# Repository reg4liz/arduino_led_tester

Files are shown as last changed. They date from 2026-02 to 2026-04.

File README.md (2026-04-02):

# arduino_led_tester
LED tester on atmega328 with adjustable current source.

## Glorious prototype
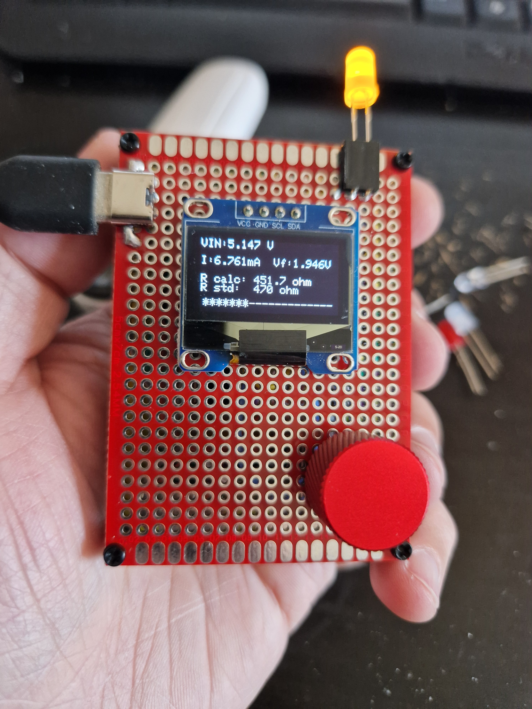
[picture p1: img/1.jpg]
Prototype


## Schematic
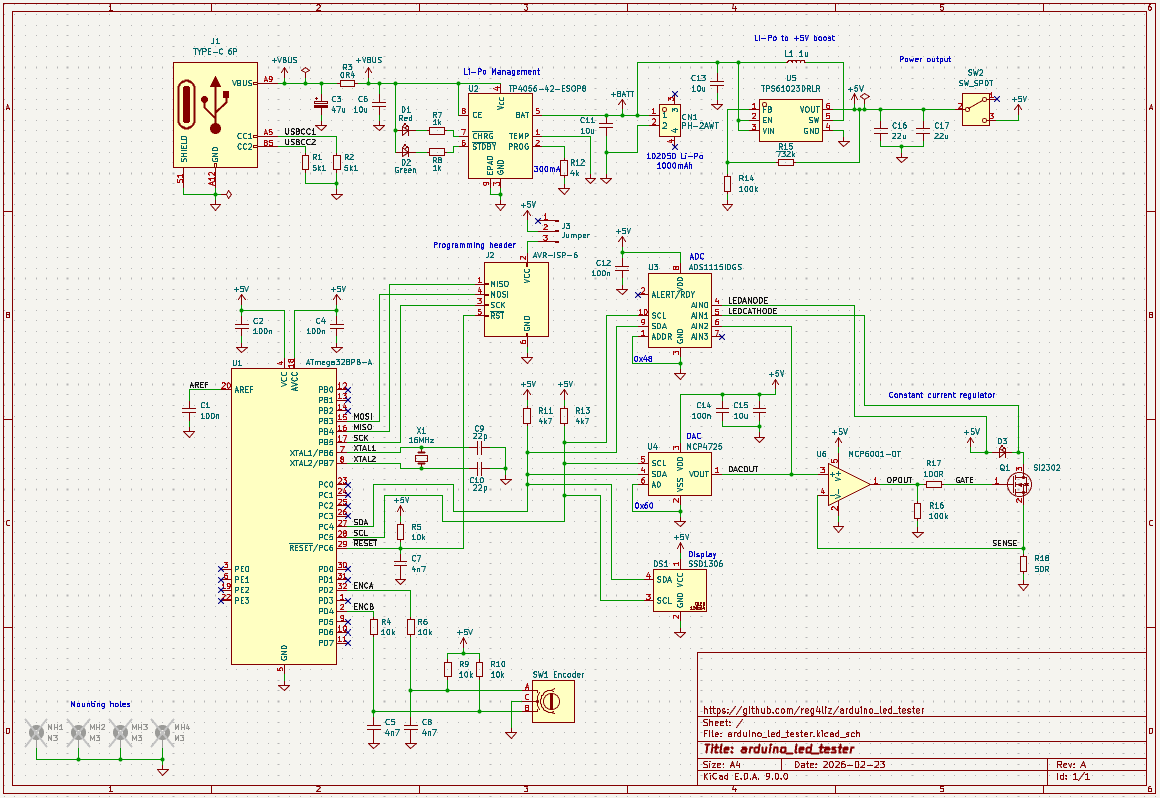
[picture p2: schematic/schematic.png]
Schematic


## Main components used for prototype
* [ATMEGA328P](https://www.digikey.com/en/products/detail/microchip-technology/ATMEGA328P-PU/1914589)
* [MCP6001 op-amp](https://www.digikey.com/es/products/detail/microchip-technology/MCP6001T-I-OT/551760)
* [SI2302CDS nmos](https://www.digikey.com/en/products/detail/vishay-siliconix/SI2302CDS-T1-GE3/1978729)
* [PEC12R-4025F-N0024 encoder](https://www.digikey.es/es/products/detail/bourns-inc/PEC12R-4025F-N0024/4499645)
* [ADS1115 ADC Module](https://aliexpress.com/item/1005006532275889.html)
* [MCP4725 DAC Module](https://aliexpress.com/item/1005007384695140.html)
* [SSD1306 128x64 OLED display](https://aliexpress.com/item/1005004355547926.html)

## TO-DO
* Full code re-write, at this time this is just a proof of concept to get it working quickly.
* Update components list.

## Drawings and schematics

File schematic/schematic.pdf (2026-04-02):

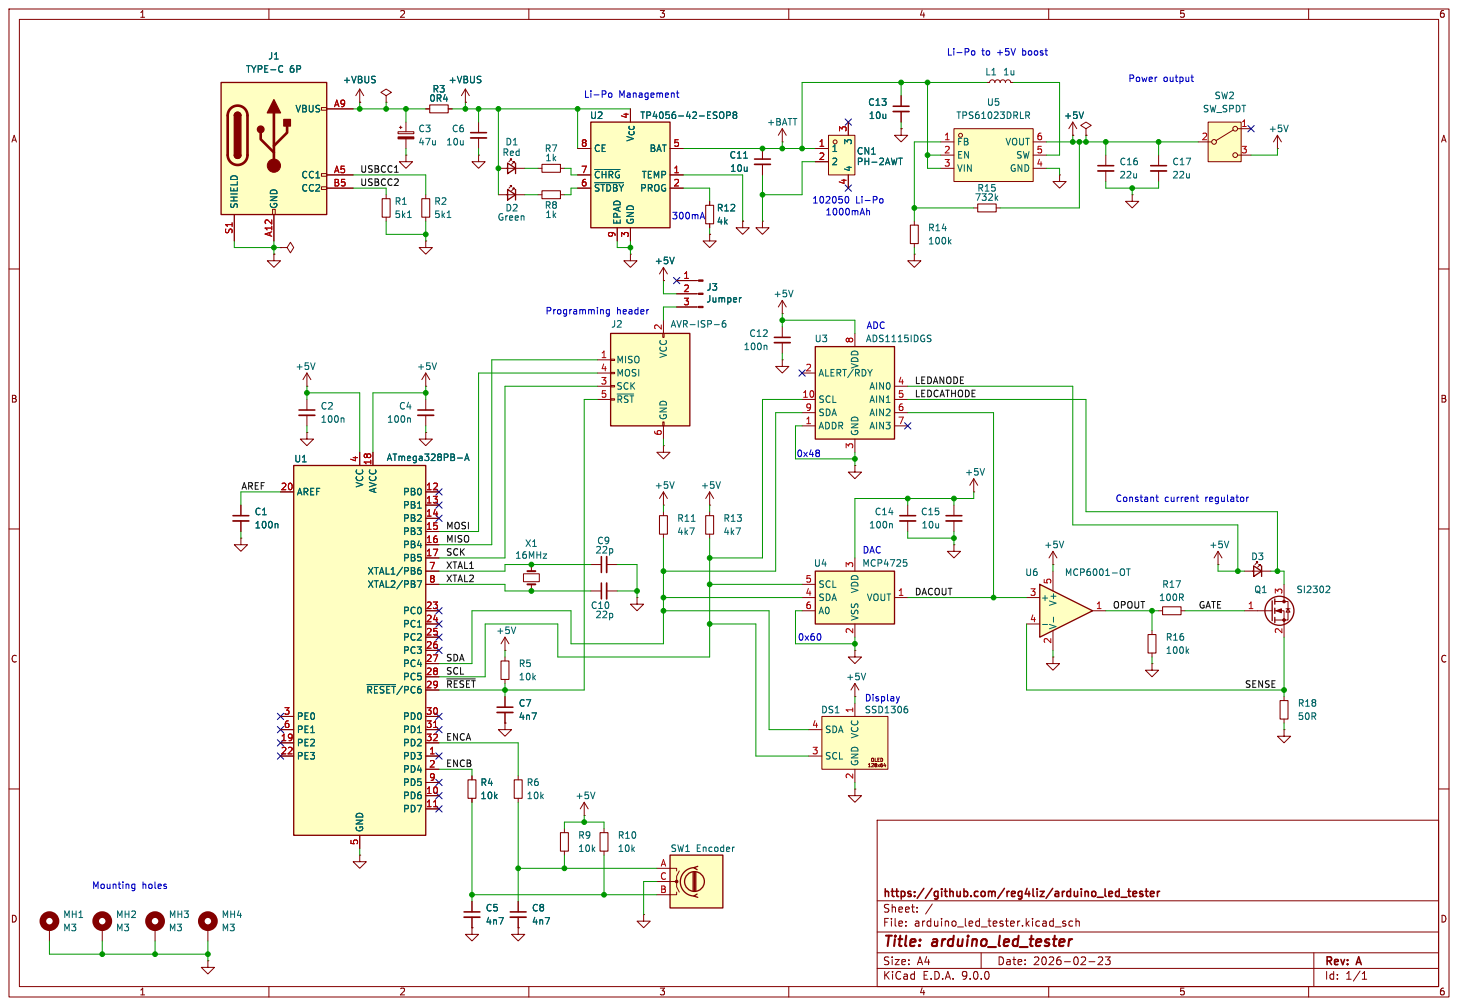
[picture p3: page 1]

Power output Constant current regulator 300mA

4 C13 U2 TP4056-42-ESOP8 10u CE 8 ~{CHRG} 7 ~{STDBY} 6 EPAD

3 ALERT/RDY 2 SCL 10 SDA 9 ADDR 1 U3 ADS1115IDGS

6 MISO 1 MOSI 4 SCK 3 ~{RST} 5

Id: 1/1 Title: arduino_led_tester File: arduino_led_tester.kicad_sch Sheet: / https://github.com/reg4liz/arduino_led_tester

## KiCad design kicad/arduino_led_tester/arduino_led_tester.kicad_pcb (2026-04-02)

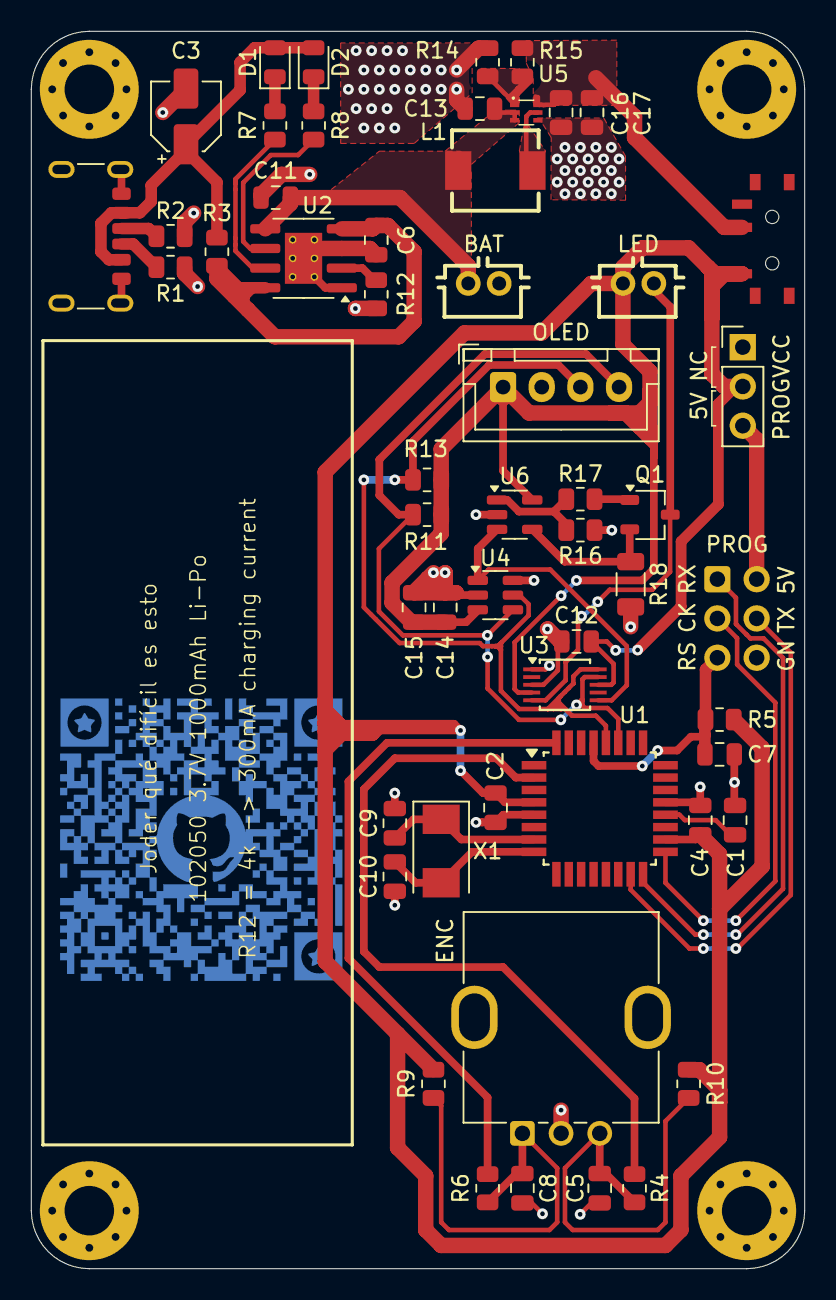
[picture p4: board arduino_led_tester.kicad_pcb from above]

Board: 2 copper layers, 50.0 x 80.0 mm, 58 parts (0 on the bottom side), 32 nets.

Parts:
BAT: PH-2AWT; CONN-TH_B2B-PH-K-S
C1, C2, C4, C12, C14: 100n; C_0805_2012Metric
C3: 47u; CP_Elec_4x5.8
C5, C7, C8: 4n7; C_0805_2012Metric
C6, C11, C13, C15: 10u; C_0805_2012Metric
C9, C10: 22p; C_0805_2012Metric
C16, C17: 22u; C_0805_2012Metric
D1: Red; LED_0805_2012Metric
D2: Green; LED_0805_2012Metric
ENC: Encoder; RotaryEncoder_Bourns_Vertical_PEC12R-3x17F-Nxxxx
J1: TYPE-C 6P; USB_C_Receptacle_GCT_USB4125-xx-x-0190_6P_TopMnt_Horizontal
L1: 1u; IND-SMD_L5.5-W5.2
LED: CONN-TH_B2B-PH-K-S
MH1, MH2, MH3, MH4: M3; MountingHole_3.2mm_M3_Pad_Via
OLED: SSD1306; JST_XH_B4B-XH-A_1x04_P2.50mm_Vertical
PROG: AVR-ISP-6; IDC-Header_2x03_P2.54mm_Vertical
PROGVCC: Jumper; PinHeader_1x03_P2.54mm_Vertical
Q1: SI2302; TSOT-23
R1, R2: 5k1; R_0805_2012Metric
R3: 0R4; R_0805_2012Metric
R4, R5, R6, R9, R10: 10k; R_0805_2012Metric
R7, R8: 1k; R_0805_2012Metric
R11, R13: 4k7; R_0805_2012Metric
R12: 4k; R_0805_2012Metric
R14, R16: 100k; R_0805_2012Metric
R15: 732k; R_0805_2012Metric
R17: 100R; R_0805_2012Metric
R18: 50R; R_1206_3216Metric
SW2: SW_SPDT; Switch_SPDT_LCSC_MSK12CO2_BDM
U1: ATmega328PB-A; TQFP-32_7x7mm_P0.8mm
U2: TP4056-42-ESOP8; SOIC-8-1EP_3.9x4.9mm_P1.27mm_EP2.41x3.3mm_ThermalVias
U3: ADS1115IDGS; TSSOP-10_3x3mm_P0.5mm
U4: MCP4725; SOT-23-6
U5: TPS61023DRLR; SOT-563_L1.6-W1.2-P0.50-LS1.6-BR
U6: MCP6001-OT; SOT-23-5
X1: 16MHz; Crystal_SMD_Abracon_ABM3-2Pin_5.0x3.2mm

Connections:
+5V: C2.1, C4.1, C12.1, C14.1, C15.1, C16.1, C17.1, LED.2 (A), OLED.1 (VCC), PROGVCC.2, R5.1, R9.1, R10.1, R11.1, R13.1, R15.2, SW2.2 (B), SW2.3 (C), U1.4 (VCC), U1.18 (AVCC), U3.4 (AIN0), U3.8 (VDD), U4.3 (VDD), U5.6 (VOUT), U6.5 (V+)
+BATT: BAT.1, C11.1, C13.1, L1.1, U2.5 (BAT), U5.2 (EN), U5.3 (VIN)
+VBUS: C3.1, C6.1, D1.2 (A), D2.2 (A), J1.A9 (VBUS), J1.B9 (VBUS), R3.1, R3.2, U2.4 (V_{CC}), U2.8 (CE)
/AREF: C1.1, U1.20 (AREF)
/DACOUT: U3.6 (AIN2), U4.1 (VOUT), U6.3 (+)
/ENCA: R6.1, U1.32 (PD2)
/ENCB: R4.1, U1.2 (PD4)
/GATE: Q1.1 (G), R17.2
/LEDCATHODE: LED.1 (K), Q1.3 (D), U3.5 (AIN1)
/MISO: PROG.1 (MISO), U1.16 (PB4)
/MOSI: PROG.4 (MOSI), U1.15 (PB3)
/OPOUT: R16.2, R17.1, U6.1
/SCK: PROG.3 (SCK), U1.17 (PB5)
/SCL: OLED.3 (SCL), R13.2, U1.28 (PC5), U3.10 (SCL), U4.5 (SCL)
/SDA: OLED.4 (SDA), R11.2, U1.27 (PC4), U3.9 (SDA), U4.4 (SDA)
/SENSE: Q1.2 (S), R18.1, U6.4 (-)
/USBCC1: J1.A5 (CC1), R2.1
/USBCC2: J1.B5 (CC2), R1.1
/XTAL1: C9.1, U1.7 (XTAL1/PB6), X1.1
/XTAL2: C10.1, U1.8 (XTAL2/PB7), X1.2
/~RESET: C7.1, PROG.5 (~RST), R5.2, U1.29 (~RESET/PC6)
GND: BAT.2, C1.2, C2.2, C3.2, C4.2, C5.2, C6.2, C7.2, C8.2, C9.2, C10.2, C11.2, C12.2, C13.2, C14.2, C15.2, C16.2, C17.2, ENC.C, J1.A12 (GND), J1.B12 (GND), J1.S1 (SHIELD), MH1.1, MH2.1, MH3.1, MH4.1, OLED.2 (GND), PROG.6 (GND), R1.2, R2.2, R12.2, R14.2, R16.1, R18.2, U1.5 (GND), U1.21 (GND), U2.1 (TEMP), U2.3 (GND), U2.9 (EPAD), U3.1 (ADDR), U3.3 (GND), U4.2 (VSS), U4.6 (A0), U5.4 (GND), U6.2 (V-)
unnamed: C5.1, ENC.B, R4.2, R10.2
unnamed: C8.1, ENC.A, R6.2, R9.2
unnamed: D1.1 (K), R7.1
unnamed: D2.1 (K), R8.1
unnamed: PROG.2 (VCC), PROGVCC.3
unnamed: R12.1, U2.2 (PROG)
unnamed: R7.2, U2.7 (~CHRG)
unnamed: R8.2, U2.6 (~STDBY)
unnamed: R14.1, R15.1, U5.1 (FB)
unnamed: L1.2, U5.5 (SW)

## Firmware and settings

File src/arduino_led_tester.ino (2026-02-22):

// arduino_led_tester.ino
// v0.1a 2026.02.22

#include <Wire.h>
#include <Adafruit_GFX.h>
#include <Adafruit_SSD1306.h>
#include <Adafruit_ADS1X15.h>
#include <Adafruit_MCP4725.h>
#include <avr/pgmspace.h>

// display
#define SCREEN_WIDTH 128
#define SCREEN_HEIGHT 64
#define OLED_RESET -1
#define SCREEN_ADDRESS 0x3C
Adafruit_SSD1306 display(SCREEN_WIDTH, SCREEN_HEIGHT, &Wire, OLED_RESET);

// encoder
#define encoder0PinA 2
#define encoder0PinB 4
volatile unsigned int encoder0Pos = 0;
volatile byte aLastState;
volatile byte bLastState;
volatile unsigned long lastUpdateTime = 0;
unsigned int prevPos = 0;
#define ACCEL_LEVEL1_THRESHOLD 50
#define ACCEL_LEVEL2_THRESHOLD 20
#define ACCEL_LEVEL3_THRESHOLD 10
#define ACCEL_LEVEL1_MULT 2
#define ACCEL_LEVEL2_MULT 4
#define ACCEL_LEVEL3_MULT 8

// adc
Adafruit_ADS1115 ads;
const float multiplier = 0.1875f;

// dac
Adafruit_MCP4725 dac;
uint16_t currentDacValue = 0;

// general
#define MAX_CURRENT_MA 20.0
#define RSENSE 50.0
#define MAX_DAC_VOLTAGE 1.0
#define DAC_MAX_VALUE 4095
#define DAC_STEP 1
// #define buttonPin 8
float ledVoltage = 0.0f;

// std E12 resistor values, to progmem at least temporarily. Display buffer alone is already chewing up ~1K of RAM
const float STANDARD_RESISTORS[] PROGMEM = {
  1.0, 1.2, 1.5, 1.8, 2.2, 2.7, 3.3, 3.9, 4.7, 5.6, 6.8, 8.2,
  10, 12, 15, 18, 22, 27, 33, 39, 47, 56, 68, 82,
  100, 120, 150, 180, 220, 270, 330, 390, 470, 560, 680, 820,
  1000, 1200, 1500, 1800, 2200, 2700, 3300, 3900, 4700, 5600, 6800, 8200,
  10000, 12000, 15000, 18000, 22000, 27000, 33000, 39000, 47000, 56000, 68000, 82000,
  100000, 120000, 150000, 180000, 220000, 270000, 330000, 390000, 470000, 500000
};

const int NUM_STANDARD_RESISTORS = sizeof(STANDARD_RESISTORS) / sizeof(STANDARD_RESISTORS[0]);

// calculate actual current from DAC voltage reading
float dacVoltageToCurrent(float dacVoltage) {
  return (dacVoltage / RSENSE) * 1000.0;
}

// check if DAC value would exceed 20mA
bool wouldExceedMaxCurrent(uint16_t proposedDacValue) {
  float proposedVoltage = (proposedDacValue / (float)DAC_MAX_VALUE) * 5.0;
  float proposedCurrent = dacVoltageToCurrent(proposedVoltage);
  return proposedCurrent > MAX_CURRENT_MA;
}

// calculate series resistor needed at given current
// R = (Vin - Vf) / I
float calculateSeriesResistor(float supplyVoltage, float ledVf, float currentMA) {
  if (currentMA <= 0.001) {
    return 999999.0;
  }
  float currentA = currentMA / 1000.0;
  float resistance = (supplyVoltage - ledVf) / currentA;
  
  if (resistance < 0) {
    return 0.0;
  }
  
  return resistance;
}

// find closest standard resistor value
float findStandardResistor(float targetResistance, float supplyVoltage, float ledVf) {
  if (targetResistance <= 0) {
    return pgm_read_float(&STANDARD_RESISTORS[NUM_STANDARD_RESISTORS - 1]);
  }
  
  float closestResistor = pgm_read_float(&STANDARD_RESISTORS[0]);
  float minDifference = abs(targetResistance - closestResistor);
  
  // find closest standard value
  for (int i = 1; i < NUM_STANDARD_RESISTORS; i++) {
    float stdValue = pgm_read_float(&STANDARD_RESISTORS[i]);
    float difference = abs(targetResistance - stdValue);
    if (difference < minDifference) {
      minDifference = difference;
      closestResistor = stdValue;
    }
  }
  
  // check if this resistor would cause > 20mA
  float resultingCurrent = ((supplyVoltage - ledVf) / closestResistor) * 1000.0;
  
  if (resultingCurrent > MAX_CURRENT_MA) {
    // find next higher standard value
    for (int i = 0; i < NUM_STANDARD_RESISTORS; i++) {
      float stdValue = pgm_read_float(&STANDARD_RESISTORS[i]);
      if (stdValue > closestResistor) {
        return stdValue;
      }
    }
    return pgm_read_float(&STANDARD_RESISTORS[NUM_STANDARD_RESISTORS - 1]);
  }
  
  return closestResistor;
}

void doEncoder() {
  byte aState = digitalRead(encoder0PinA);
  byte bState = digitalRead(encoder0PinB);
  
  if (aState != aLastState) {
    unsigned long currentTime = millis();
    unsigned long timeDiff = currentTime - lastUpdateTime;
    lastUpdateTime = currentTime;
    
    unsigned int increment = DAC_STEP;
    
    if (timeDiff < ACCEL_LEVEL3_THRESHOLD) {
      increment = DAC_STEP * ACCEL_LEVEL3_MULT;
    } else if (timeDiff < ACCEL_LEVEL2_THRESHOLD) {
      increment = DAC_STEP * ACCEL_LEVEL2_MULT;
    } else if (timeDiff < ACCEL_LEVEL1_THRESHOLD) {
      increment = DAC_STEP * ACCEL_LEVEL1_MULT;
    }
    
    if (aState == bState) {
      // going backward
      if (encoder0Pos >= increment) {
        encoder0Pos -= increment;
      } else {
        encoder0Pos = 0;
      }
    } else {
      // going forward
      unsigned int proposedValue = encoder0Pos + increment;
      if (proposedValue > DAC_MAX_VALUE) {
        proposedValue = DAC_MAX_VALUE;
      }
      
      if (!wouldExceedMaxCurrent(proposedValue)) {
        encoder0Pos = proposedValue;
      }
    }
    
    aLastState = aState;
  }
  
  bLastState = bState;
}

void setup() {
  Serial.begin(9600);

  // button
  // pinMode(buttonPin, INPUT_PULLUP);
  
  // encoder
  pinMode(encoder0PinA, INPUT_PULLUP); 
  pinMode(encoder0PinB, INPUT_PULLUP); 
  aLastState = digitalRead(encoder0PinA);
  bLastState = digitalRead(encoder0PinB);
  attachInterrupt(digitalPinToInterrupt(encoder0PinA), doEncoder, CHANGE);

  // i2c
  Wire.begin();
    
  // display
  if(!display.begin(SSD1306_SWITCHCAPVCC, SCREEN_ADDRESS)) {
    Serial.println(F("SSD1306 allocation failed"));
    for(;;);
  }
  Serial.println("Display initialized!");
  display.clearDisplay();
  display.setTextSize(1);
  display.setTextColor(SSD1306_WHITE);
  // display.setCursor(0,0);
  // display.println("LED Tester");
  display.display();

  // adc
  ads.setGain(GAIN_TWOTHIRDS);
  ads.begin(0x48);

  // dac
  dac.begin(0x60);
  dac.setVoltage(0, false);
  currentDacValue = 0;
}

void loop() {
  unsigned int pos;
  noInterrupts();
  pos = encoder0Pos;
  interrupts();

  currentDacValue = pos;
  dac.setVoltage(currentDacValue, false);
  
  int16_t adc0 = ads.readADC_SingleEnded(0);
  int16_t adc1 = ads.readADC_SingleEnded(1);
  int16_t adc2 = ads.readADC_SingleEnded(2);
  
  float vin = adc0 * multiplier / 1000.0;
  float ledCathode = adc1 * multiplier / 1000.0;
  float dacVoltage = adc2 * multiplier / 1000.0;
  
  float actualCurrent = dacVoltageToCurrent(dacVoltage);
  
  if(ledCathode >= 0.1) { 
    ledVoltage = vin - ledCathode;
  } else {
    ledVoltage = 0.0;
  }
  
  float seriesResistor = calculateSeriesResistor(5.0, ledVoltage, actualCurrent);
  float standardResistor = findStandardResistor(seriesResistor, 5.0, ledVoltage);
  
  Serial.print("DAC Value: "); Serial.print(currentDacValue);
  Serial.print(" | DAC V: "); Serial.print(dacVoltage, 3); Serial.print("V");
  Serial.print(" | Actual I: "); Serial.print(actualCurrent, 3); Serial.print("mA");
  Serial.print(" | VIN: "); Serial.print(vin, 3); Serial.print("V");
  Serial.print(" | LED Vf: "); Serial.print(ledVoltage, 3); Serial.print("V");
  Serial.print(" | R calc: "); Serial.print(seriesResistor, 1); Serial.print("Ω");
  Serial.print(" | R std: "); Serial.print(standardResistor, 0); Serial.println("Ω");
  
  display.clearDisplay();
  display.setCursor(1, 0);
  display.setTextSize(1);
  
  display.print("VIN:");
  display.print(vin, 3);
  display.println(" V");
  display.setCursor(1, 15);
  display.print("I:");
  display.print(actualCurrent, 3);
  display.print("mA  Vf:");
  display.print(ledVoltage, 3);
  display.println("V");
  
if (ledVoltage > 0.3 /*&& actualCurrent > 0.5*/) {
  display.setCursor(1, 31);
  display.print("R calc: ");
  if (seriesResistor < 1000) {
    display.print(seriesResistor, 1);
    display.print(" ohm");
  } else if (seriesResistor < 1000000) {
    display.print(seriesResistor / 1000.0, 2);
    display.print("k ohm");
  } else {
    display.print(seriesResistor / 1000000.0, 2);
    display.print("M ohm");
  }
  
  display.setCursor(1, 39);
  display.print("R std:  ");
  if (standardResistor < 1000) {
    display.print(standardResistor, 0);
    display.print(" ohm");
  } else if (standardResistor < 1000000) {
    display.print(standardResistor / 1000.0, 2);
    display.print("k ohm");
  } else {
    display.print(standardResistor / 1000000.0, 2);
    display.print("M ohm");
  }
} else {
  display.setCursor(1, 31);
  display.println("No LED detected");
}
  
  // display.println();
  // display.print("OPAMP+IN:");
  // display.print(dacVoltage, 3);
  // display.println(" V");

  display.setCursor(3, 52);
  int numAsterisks = (int)(actualCurrent + 0.5);  // Round to nearest integer
  if (numAsterisks > 20) numAsterisks = 20;
  if (numAsterisks < 0) numAsterisks = 0;
  int numDashes = 20 - numAsterisks;

  for (int i = 0; i < numAsterisks; i++) {
    display.print("*");
  }

  for (int i = 0; i < numDashes; i++) {
    display.print("-");
  }

  display.display();
  
  prevPos = pos;
}

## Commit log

2026-04-02 pcb design ready
    upload kicad files, schematics and gerbers
    [arduino_led_tester.kicad_pcb, arduino_led_tester.kicad_sch, arduino_led_tester_cover.kicad_pcb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]
2026-04-02 updated readme
    include schematic and update to-do list
2026-04-02 converted gerbers to zip
2026-04-02 updates to cover pcb and fabrication files
    [arduino_led_tester_cover.kicad_pcb]
